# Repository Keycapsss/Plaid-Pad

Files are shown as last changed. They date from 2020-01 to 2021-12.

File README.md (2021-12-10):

# Plaid-Pad



A 4x4 numpad/macro pad with only through hole components. It supports up to 4 rotary encoder. The positions for the encoder are interchangeable with keyboard switches.  

---

- [**Build guide**](./buildguide_en.md)
- [QMK Firmware](#qmk-firmware)
- [Bootloader](#bootloader)
- [Changelog](#changelog)
- [3D printing parts](./3d-print) (simple case)
- [Laser cut drawings](./lasercut) (guard plate, dampening foam)

---

## Keymap



Below you can see the possible positions for the 4 rotary encoder (Rev1 only 2).  
*If you place a encoder in the top left corner (E1), you can't use another encoder in the lower right corner.*

```text
Rev2                      Rev1
,-----------------------,   ,-----------------------,
|  E1 |  E2 |  E3 |  E4 |   |  E1 |     |     |  E2 |
|-----+-----+-----+-----|   |-----+-----+-----+-----|
|     |     |     |  E3 |   |     |     |     |     |
|-----+-----+-----+-----|   |-----+-----+-----+-----|
|     |     |     |  E2 |   |     |     |     |     |
|-----+-----+-----+-----|   |-----+-----+-----+-----|
|     |     |     |  E1 |   |     |     |     |     |
`-----------------------'   `-----------------------'
```  

- Encoder E1 performs a tap on KC_F17 and KC_F18
- Encoder E2 performs a tap on KC_F19 and KC_F20
- Encoder E3 performs a tap on KC_F21 and KC_F22
- Encoder E4 performs a tap on KC_F23 and KC_F24

The F17-F24 keys are intended to be customized via [Karabiner-Elements](https://github.com/pqrs-org/Karabiner-Elements) (OSX), or [AutoHotkey](https://github.com/Lexikos/AutoHotkey_L) (WIN).

It's a great companion to the Plaid keyboard by [hsgw](https://github.com/hsgw/) and heavily inspired by it.

- Keyboard Maintainer: BenRoe [Github](https://github.com/BenRoe) / [Twitter](https://twitter.com/keycapsss)
- Hardware Supported: ATmega328P with VUSB ([see Bootloader section](#Bootloader))
- Hardware Availability: [Keycapsss.com](https://keycapsss.com)

## QMK Firmware

_Bootloader ([USBaspLoader](https://github.com/baerwolf/USBaspLoader)) and Firmware ([via keymap](https://github.com/qmk/qmk_firmware/tree/master/keyboards/keycapsss/plaid_pad)) are already on the ATmega328P chip._

### QMK with VIAL support (support for rotary encoder)

_Plaid-Pad Kit's Rev3 shipped with preflashed VIAL firmware._
_If you have a Rev2 Plaid-Pad, or want to re-flash the VIAL firmware again, you can find a compiled firmware file here ([Rev2]([keycapsss_plaid_pad_rev2_vial.hex](https://minhaskamal.github.io/DownGit/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)), [Rev3]([keycapsss_plaid_pad_rev3_vial.hex](https://minhaskamal.github.io/DownGit/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)))

1. Flash pre-compiled firmware on the Plaid-Pad with [QMK Toolbox](https://github.com/qmk/qmk_toolbox/releases) ([How to enter Bootloader Mode](#enter-bootloader-mode-to-flash-a-new-firmware)).
2. Download the VIAL software from [here](https://get.vial.today)
3. Connect the Plaid-Pad to the computer with a USB cable (Reconnect after flashing the firmware)
4. Open VIAL and change the keymap to your needs (automatic save)

### QMK with VIA support (no rotary encoder support)

_Plaid-Pad Kit's shipped before 11.09.2020 are flashed with the QMK Default Keymap._
_To use VIA, compile the VIA Keymap with the following command and flash it with [QMK Toolbox](https://github.com/qmk/qmk_toolbox/releases) on the Plaid-Pad ([enter Bootloader Mode](#enter-bootloader-mode-to-flash-a-new-firmware))._

```bash
qmk compile -kb keycapsss/plaid_pad -km via
```

1. Download the VIA software from [here](https://github.com/the-via/releases/releases/latest)
2. Connect the Plaid-Pad to the computer with a USB cable
3. Open VIA, switch to the `CONFIGURE` tab and change the keymap to your needs (automatic save)

_The current VIA version can't change the rotary encoder function._

### QMK Default Keymap

Make example for this keyboard (after [setting up your build environment](https://docs.qmk.fm/#/getting_started_build_tools)):

```bash
make keycapsss/plaid_pad:default
```

or

```bash
qmk compile -kb keycapsss/plaid_pad -km default
```

Flashing example for this keyboard:

```bash
make keycapsss/plaid_pad:default:flash
```

or

```bash
qmk flash -kb keycapsss/plaid_pad -km default
```

See the [build environment setup](https://docs.qmk.fm/#/getting_started_build_tools) and the [make instructions](https://docs.qmk.fm/#/getting_started_make_guide) for more information. Brand new to QMK? Start with the [Complete Newbees Guide](https://docs.qmk.fm/#/syllabus).

You can find the rotary encoder code [here](https://github.com/qmk/qmk_firmware/blob/95bbd799a4f86dac37fdf2354e008d2fed7f6660/keyboards/keycapsss/plaid_pad/keymaps/via/keymap.c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).

## Bootloader

- same `usbasploader` as used for Plaid ([Instructions](https://github.com/hsgw/plaid/blob/master/doc/en/bootloader.md), [Repository](https://github.com/hsgw/USBaspLoader/tree/plaid))

### Enter Bootloader Mode (to flash a new firmware)

- Plug in the USB cable
- Push and hold RESET switch
- Push and hold BOOT switch
- Release RESET switch
- Release BOOT switch

alternative method:

- Unplug the USB cable
- Hold down the BOOT switch
- Plug in the USB cable
- Release the BOOT switch

alternative method ([Bootmagic Lite](https://docs.qmk.fm/#/feature_bootmagic?id=bootmagic-lite)):

- Unplug the USB cable
- Hold down the most top left key
- Plug in the USB cable
- Release the most top left key

If you succeed to enter bootloader mode, you can see usbasp in device manager, or `*** USBAsp device connected` in [QMK Toolbox](https://github.com/qmk/qmk_toolbox).

## CHANGELOG

### Rev1

- Initial pcb design
- Optional up to 2 Rotary Encoder

### Rev2 (Rev1.1)

- Pcb's with the label Rev1.1 are Rev2 (fixed with the second ordered batch)
- Optional: up to 4 Rotary Encoder
- Support for 3pin switches with the new top plate
- Add a small PLAID-PAD text beneath the USB-C connector

### Rev2.1

- Bigger solder pads for the USB-C connector
- Support for Choc V2 switches _(issue that the keycap touch the mounting screw, if bottoming out)_
- Changed case mounting style _(spacer go through the pcb and screwed on the top and bottom plate)_

### Rev3

- Support for a SSD1306 oled display (I2C Pins C4/C5)
- Removed the 2 indicator LEDs (Pin C4/C5)
- Added a power indicator LED
- Changed case mounting style back to the previous style (spacer mounted between mid PCB and bottom plate) - fix ChocV2 issue from REV2.1

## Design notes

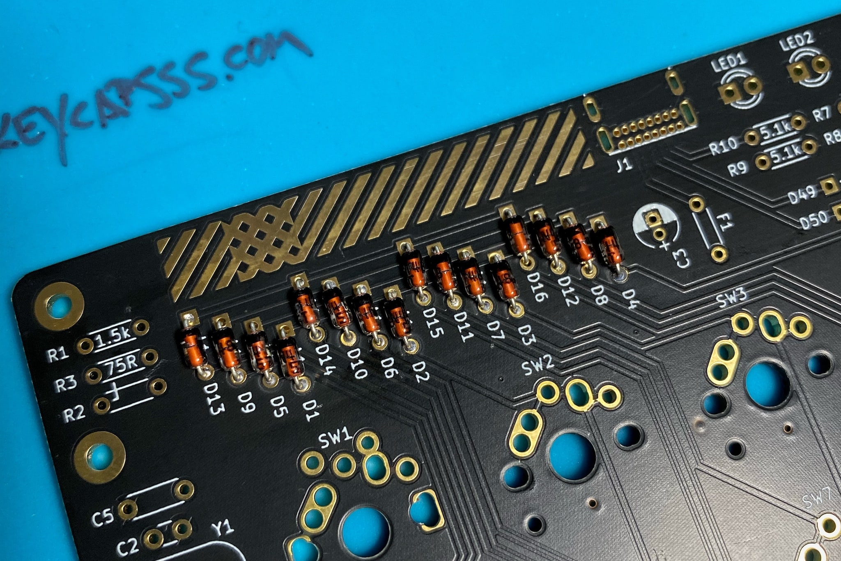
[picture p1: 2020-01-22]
img/plaid-pad-1N4148-diodes-2.jpg

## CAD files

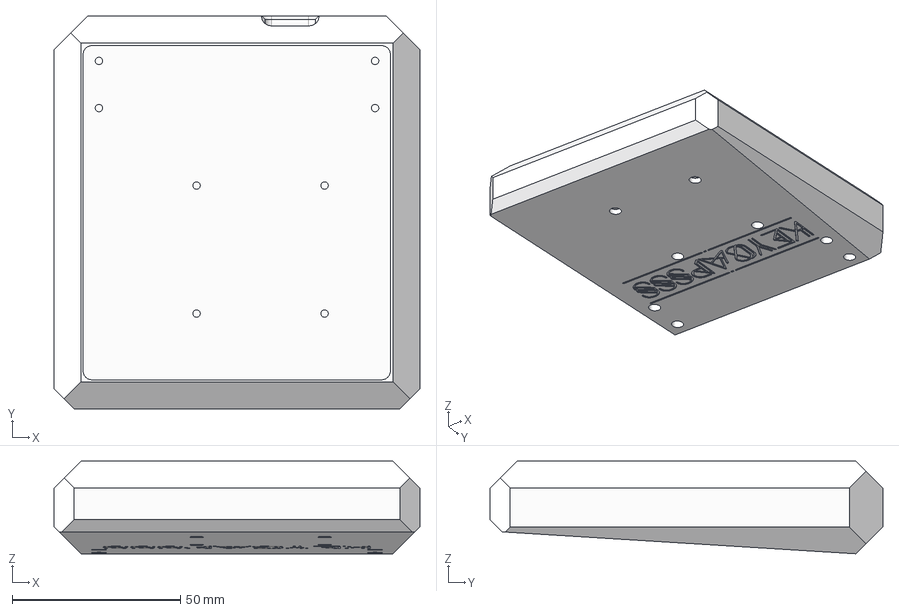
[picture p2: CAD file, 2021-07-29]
3d-print/angled-hexa-case/plaid-pad-case-hexa.step
108.7 x 116.7 x 27.5 mm

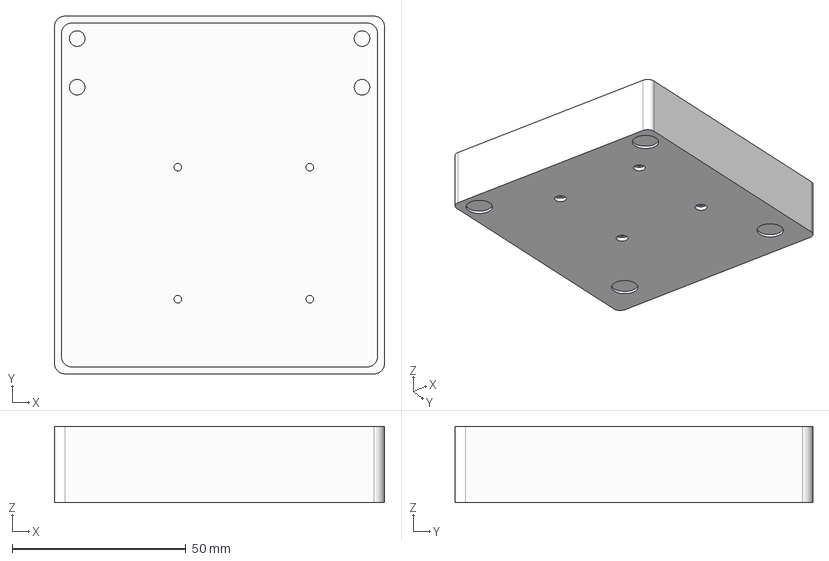
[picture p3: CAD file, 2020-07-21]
3d-print/IvoGoman/Plaid-Pad Case MX Hi-Pro Simple.step
95.0 x 103.0 x 22.0 mm

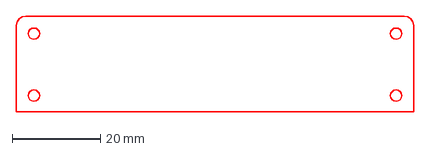
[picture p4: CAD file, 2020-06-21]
lasercut/plaid-pad-guard-cover.dxf
89.8 x 21.6 mm

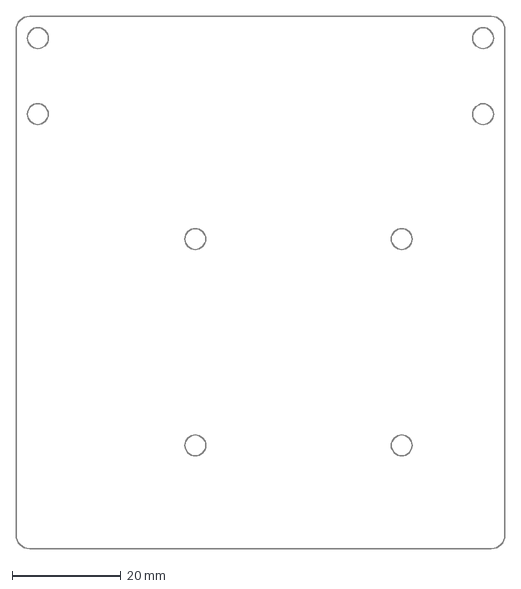
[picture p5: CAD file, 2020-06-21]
lasercut/plaid-pad-foam.dxf
90.0 x 98.0 mm

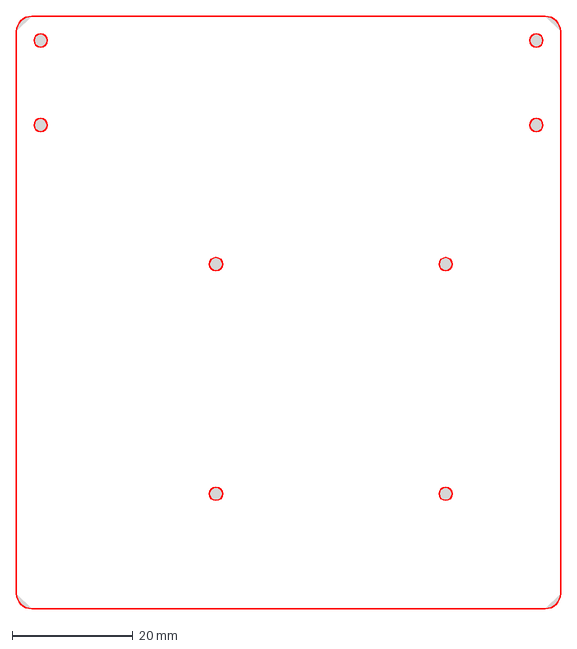
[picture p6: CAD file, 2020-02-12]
lasercut/plaid-pad-bottom-plate.dxf
90.0 x 98.0 mm

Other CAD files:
3d-print/Plaid-Pad Case MX Hi-Pro Simple.step
3d-print/IvoGoman/Plaid-Pad Case MX Hi-Pro Simple.f3d
3d-print/IvoGoman/Plaid-Pad Case MX Hi-Pro Simple.stl
3d-print/Plaid-Pad Case MX Hi-Pro Simple.f3d
3d-print/Plaid-Pad Case MX Hi-Pro Simple.stl
3d-print/angled-hexa-case/plaid-pad-case-hexa.3mf
3d-print/angled-hexa-case/plaid-pad-case-hexa.f3d
3d-print/angled-hexa-case/plaid-pad-case-hexa.stl

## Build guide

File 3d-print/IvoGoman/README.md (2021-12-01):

# Simple Case

Based on the original Simple Case design.

## Changes

1. Added notches for up to 1cm diameter bumpons on the bottom of the case
2. Added notches to the inside of the case. Not strictly necessary but makes the case compatible with the screws and stand-offs included in the kit. Otherwise you can simple use 4 additional 4mm M2 screws.

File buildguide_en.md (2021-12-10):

# Build guide for the Plaid-Pad

## Solder the through hole parts

### Diodes 1N4148 (D1-D16)

Diodes are __polarized__. The black line on the diode (cathode) must face the squared solder pad.
The 1N4148 diodes look similar as Zener diodes - so make sure that you don't confuse both diodes.

You can use some tape, as show in the image, to hold the diodes in place and solder all in one pass.

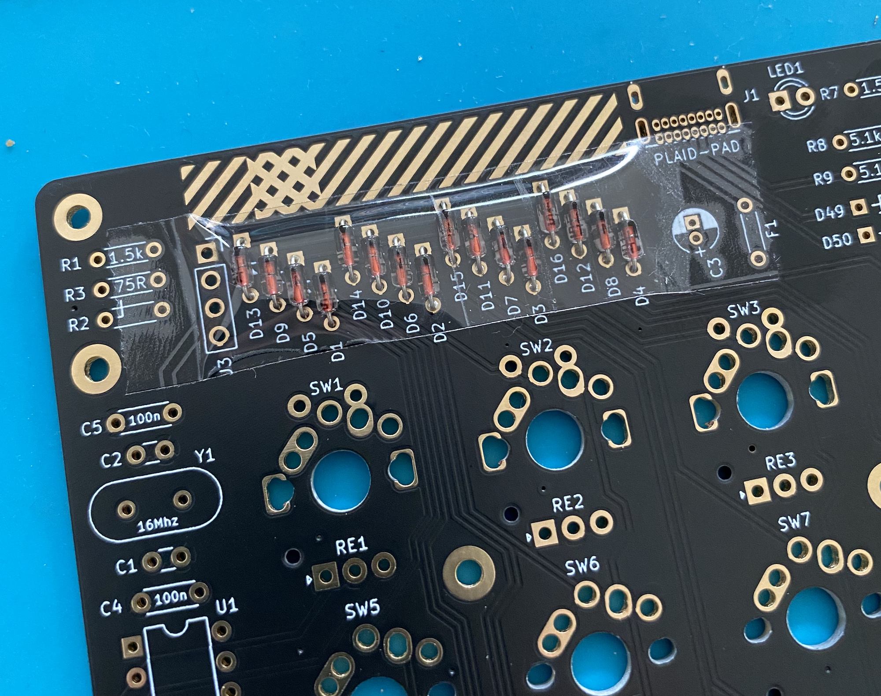
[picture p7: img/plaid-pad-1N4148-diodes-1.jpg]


### Zener diodes (D49, D50)

The diodes are __polarized__ where the black line on the diode (cathode) must face the squared solder pad.
The 1N4148 diodes look similar as Zener diodes - so make sure that you don't confuse both diodes.

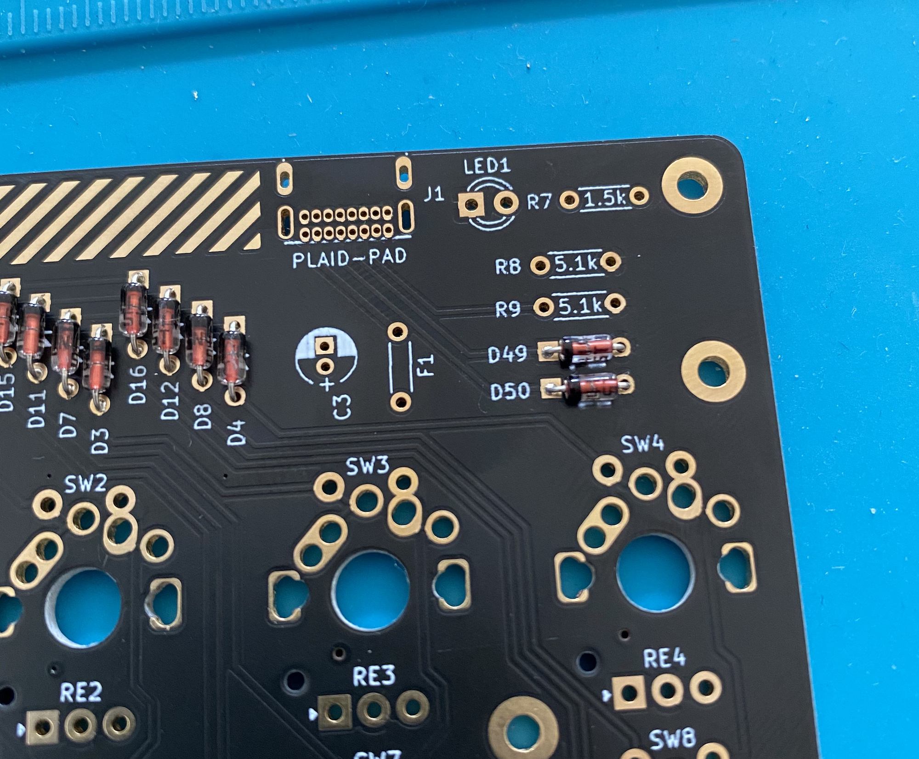
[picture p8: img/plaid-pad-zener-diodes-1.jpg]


### Resettable fuse (F1)

Attach and solder the fuse to `F1`. After soldering, bend the fuse like in the image.

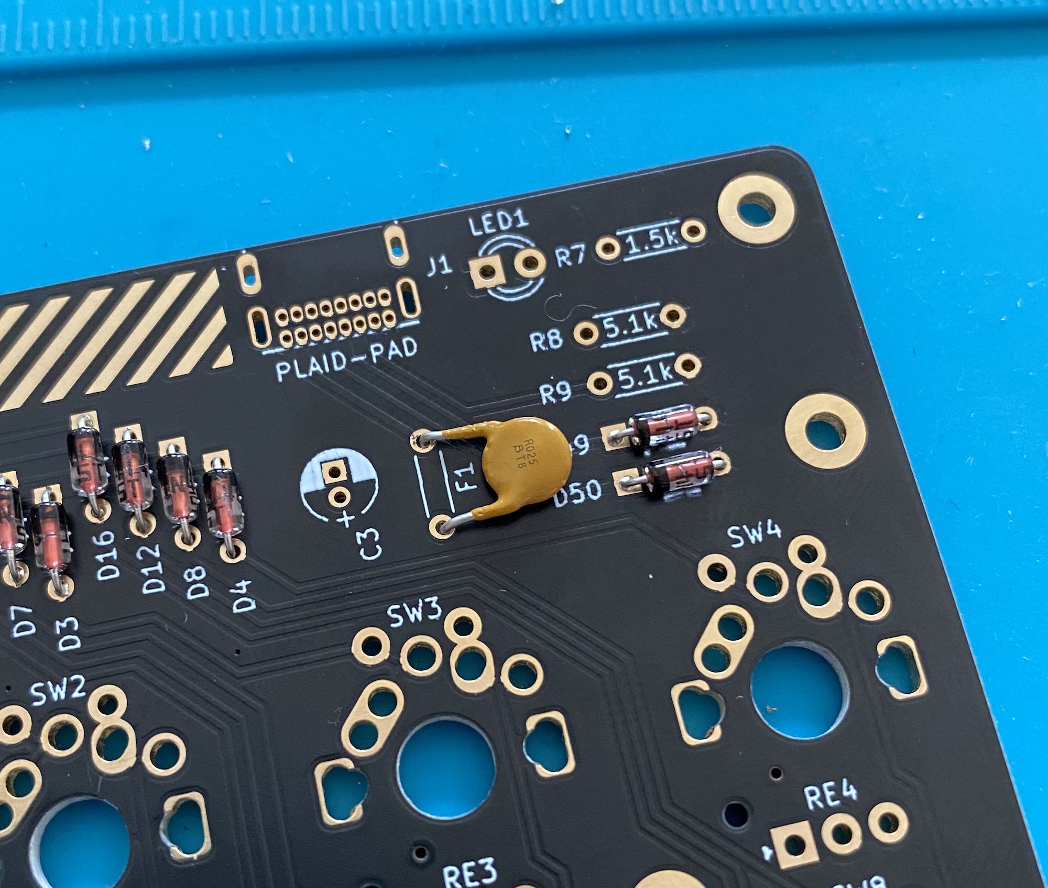
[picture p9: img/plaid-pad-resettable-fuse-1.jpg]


### Electrolytic capacitor (C3)

The Electrolytic capacitor is __polarized__. The short leg is cathode which needs to be attached to the square pad on the PCB.

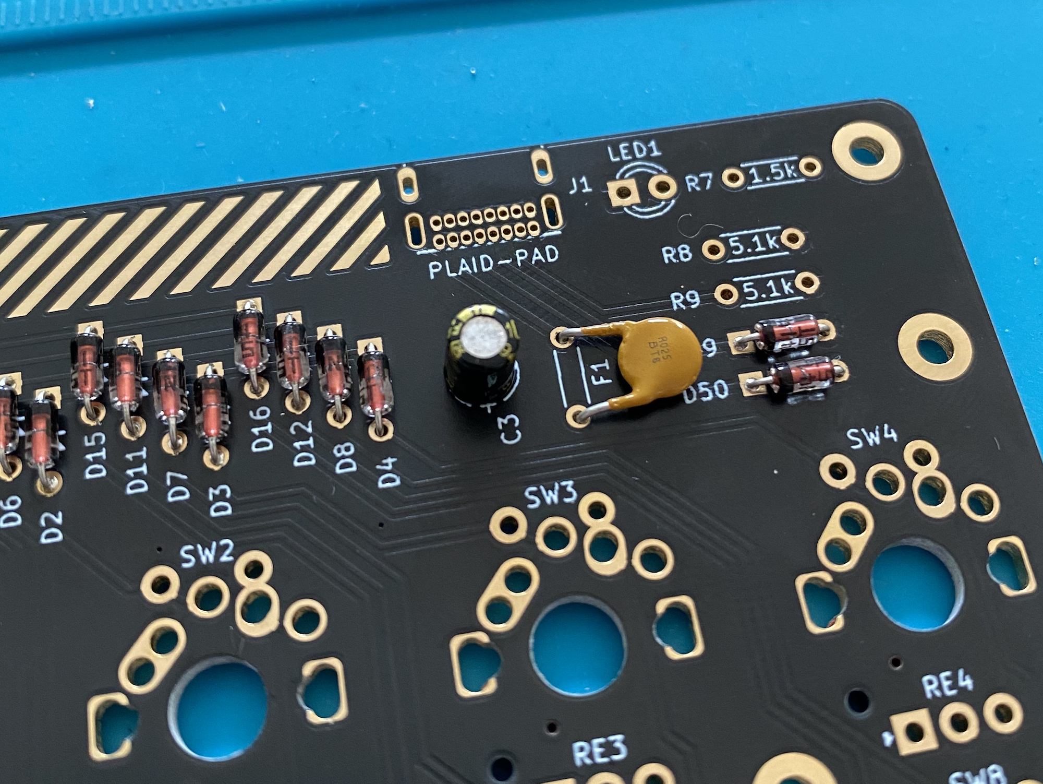
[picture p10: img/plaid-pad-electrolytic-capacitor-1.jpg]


### Resistors 1.5k Ohm (R1, R7)

Attach the resistors with following colors from left to right:

- brown, green, black, brown, brown

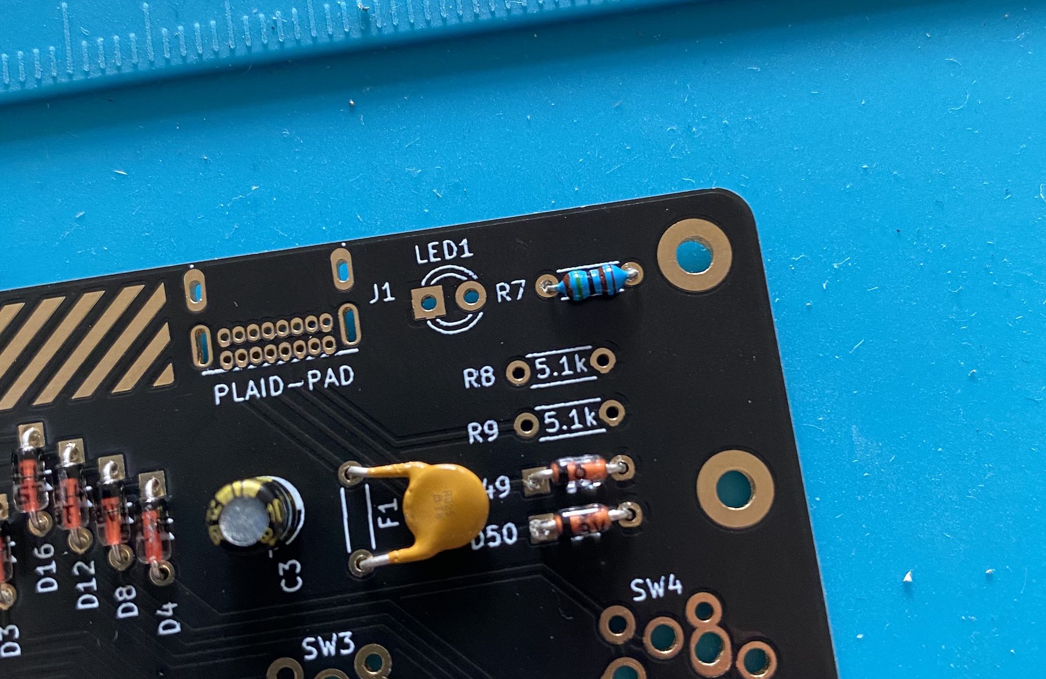
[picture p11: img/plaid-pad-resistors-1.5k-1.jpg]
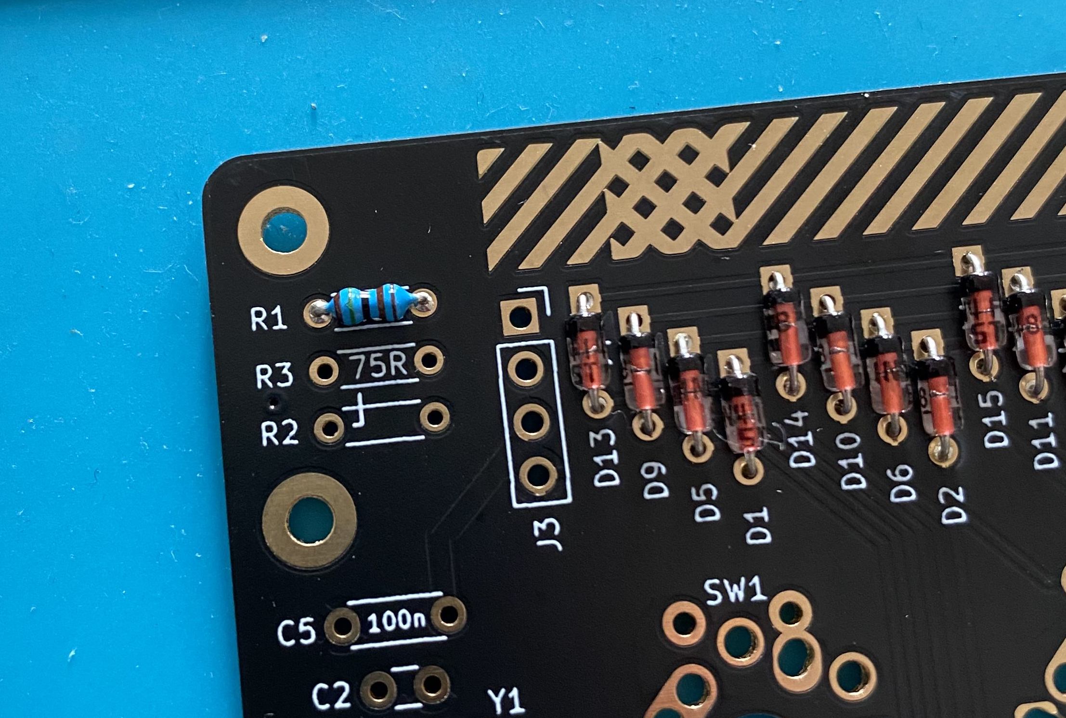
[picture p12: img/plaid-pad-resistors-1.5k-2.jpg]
 

### Resistors 75 Ohm (R2, R3)

Attach the resistors with following colors from left to right:

- brown, gold, black, green, purple

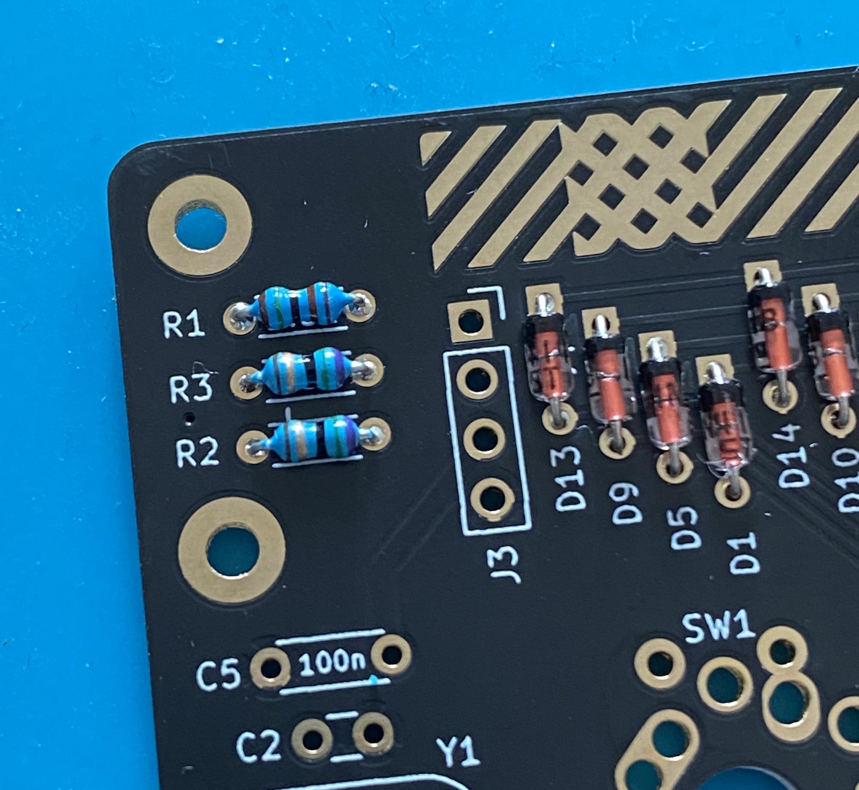
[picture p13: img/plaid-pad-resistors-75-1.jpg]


### Resistors 10k Ohm (R4)

Attach the resistors with following colors from left to right:

- brown, black, black, red, brown

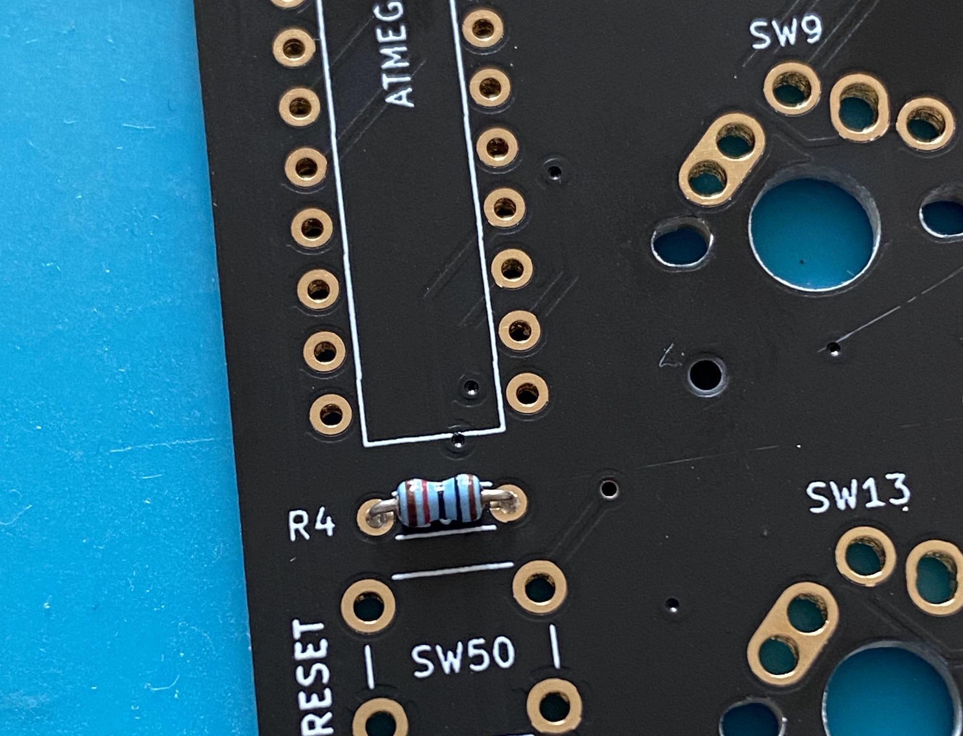
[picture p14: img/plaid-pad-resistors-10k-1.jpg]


### Resistors 5.1k Ohm (R8, R9)

Attach the resistors with following colors from left to right:

- green, brown, black, brown, brown

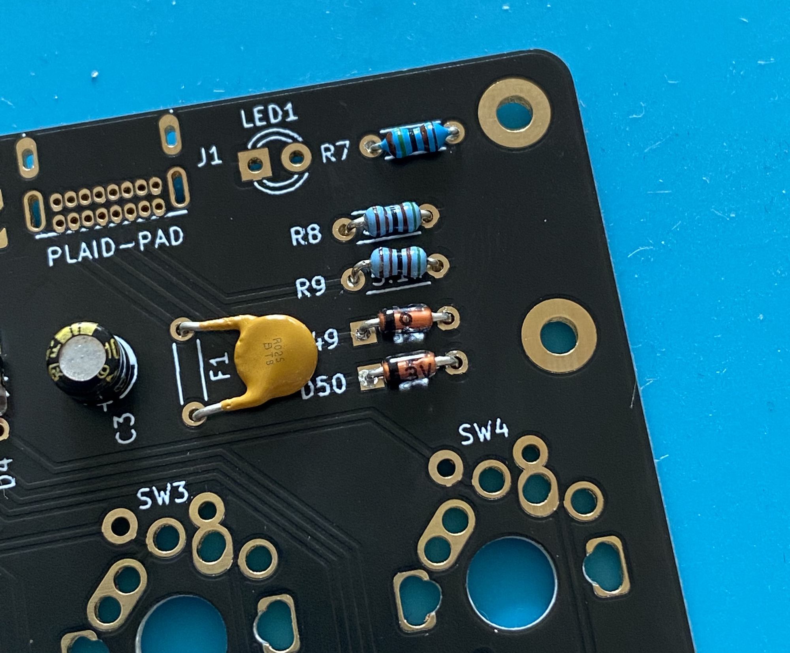
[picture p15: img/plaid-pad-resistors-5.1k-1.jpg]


### USB-C connector (J1)

Double check that there are no short cuts between the solder pads.
A magnifier is handy for this task.

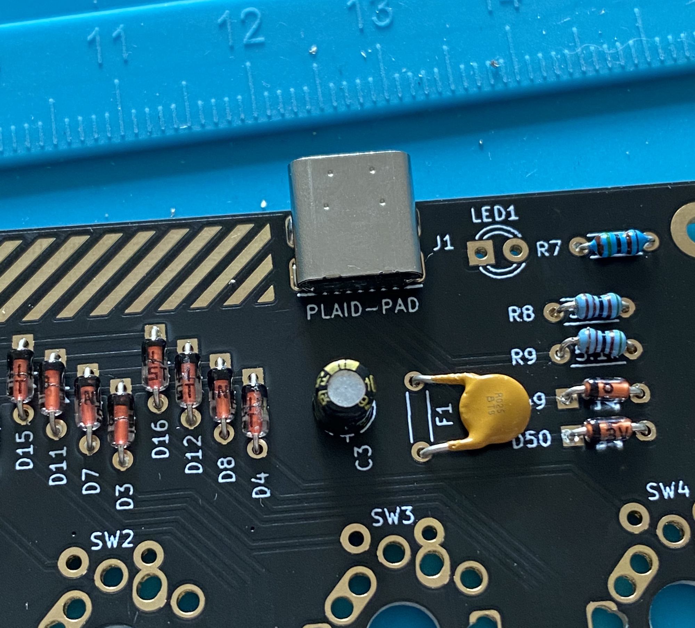
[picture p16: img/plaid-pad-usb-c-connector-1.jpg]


### Optional: LED (LED1)

The LEDs are __polarized__. The short leg is the cathode which needs to be attached to the square pad on the PCB

`LED1` indicates that the Plaid-Pad is powered and constantly on.

If you don't want a constant red light on your Plaid-Pad, don't solder this LED.

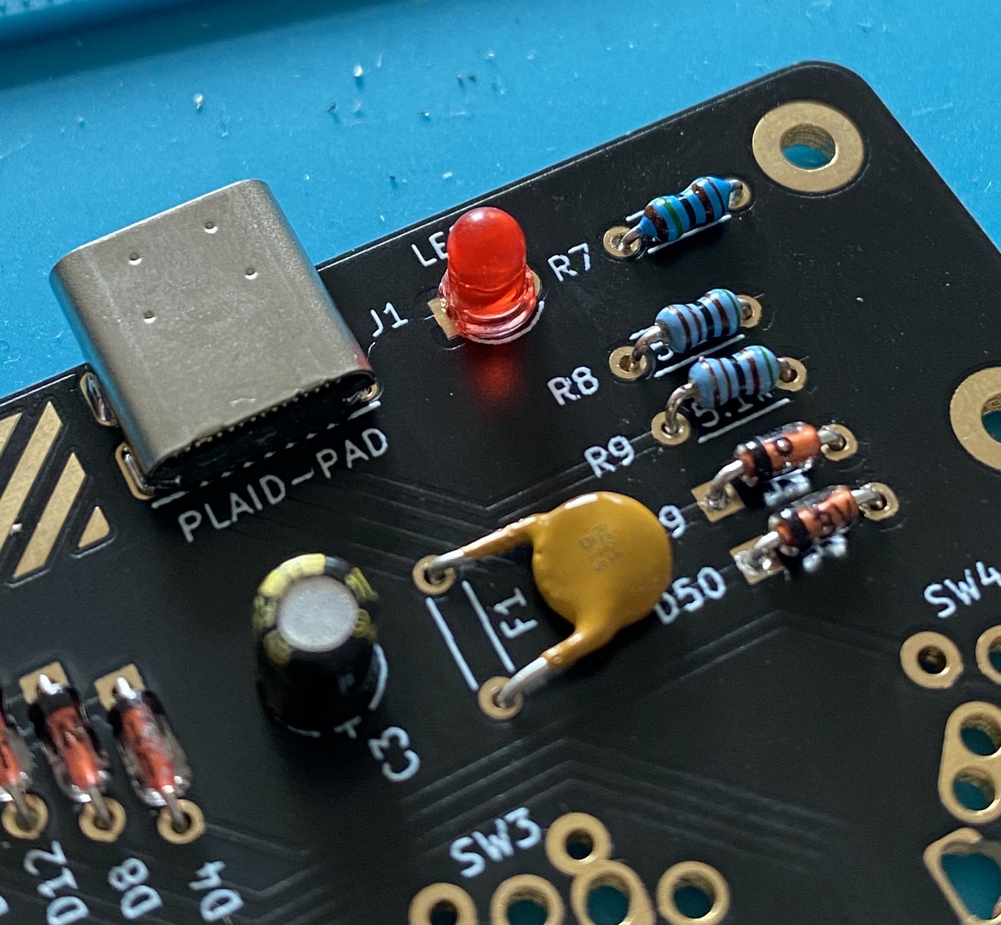
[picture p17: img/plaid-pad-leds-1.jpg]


### Crystal (Y1)

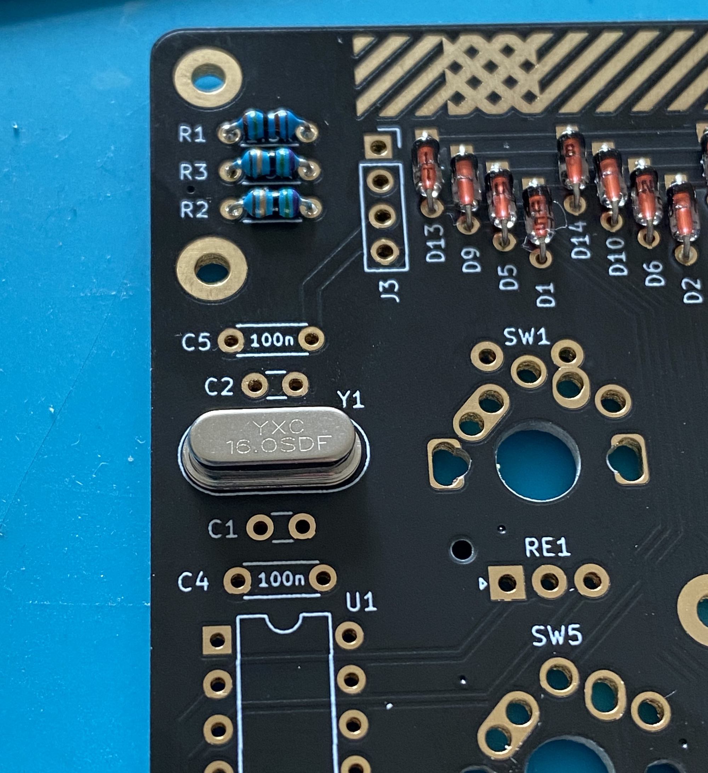
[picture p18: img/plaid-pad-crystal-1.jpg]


### Capacitors 22pF (C1, C2)

They have a small pitch (2.5mm).

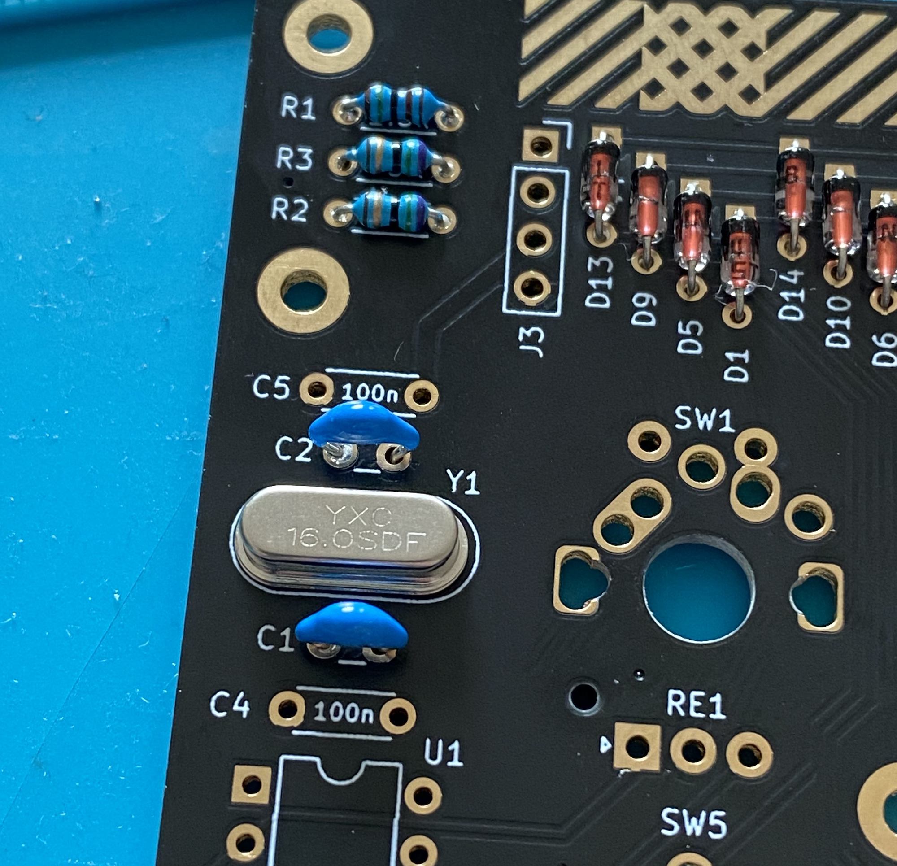
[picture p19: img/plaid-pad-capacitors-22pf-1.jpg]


### Capacitors 0.1uF (C4, C5)

These have a larger pitch of 5mm.

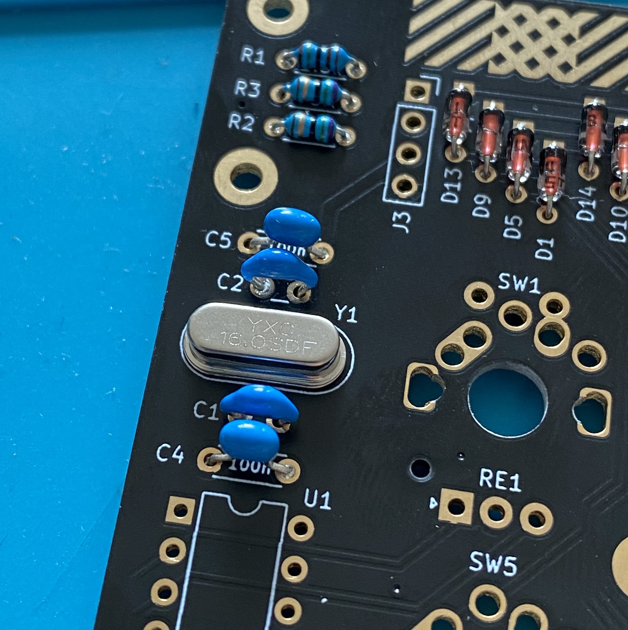
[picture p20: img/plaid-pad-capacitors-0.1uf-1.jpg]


### IC socket U1

The IC socket is __polarized__. Check the notch on the silk and the IC Socket.

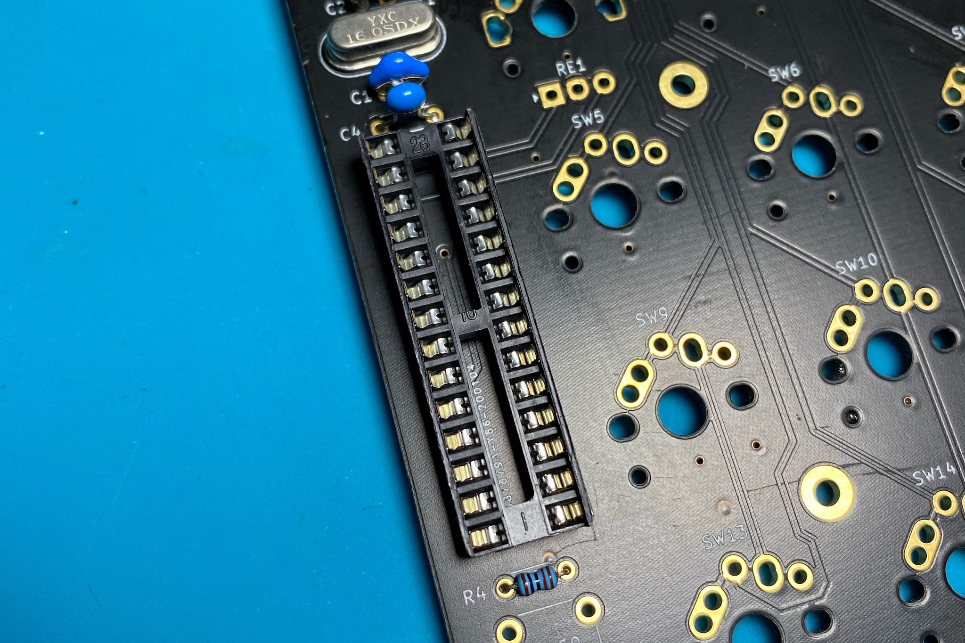
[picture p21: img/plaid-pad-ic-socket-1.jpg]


### Tactile switch (SW50/RESET, SW51/BOOT)

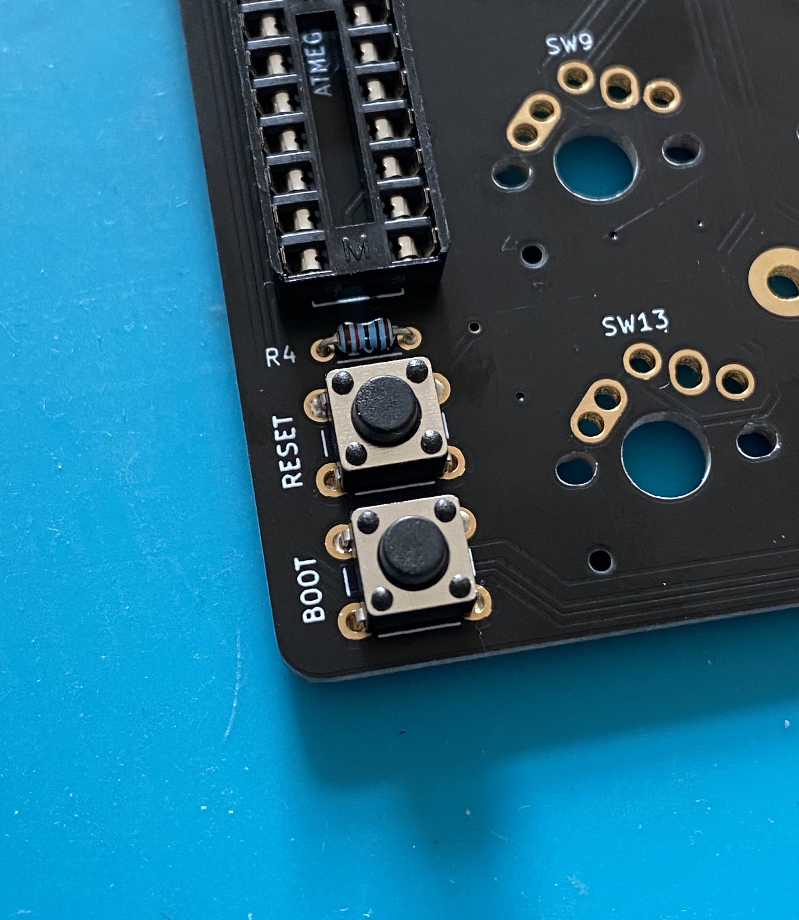
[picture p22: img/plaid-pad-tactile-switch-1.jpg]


### ATMEGA328p chip

The ATMEGA328 has to be attached in a __specific direction__. Check the notch on the chip and IC Socket - they need to match. Here, the notch faces the crystal at `Y1`.

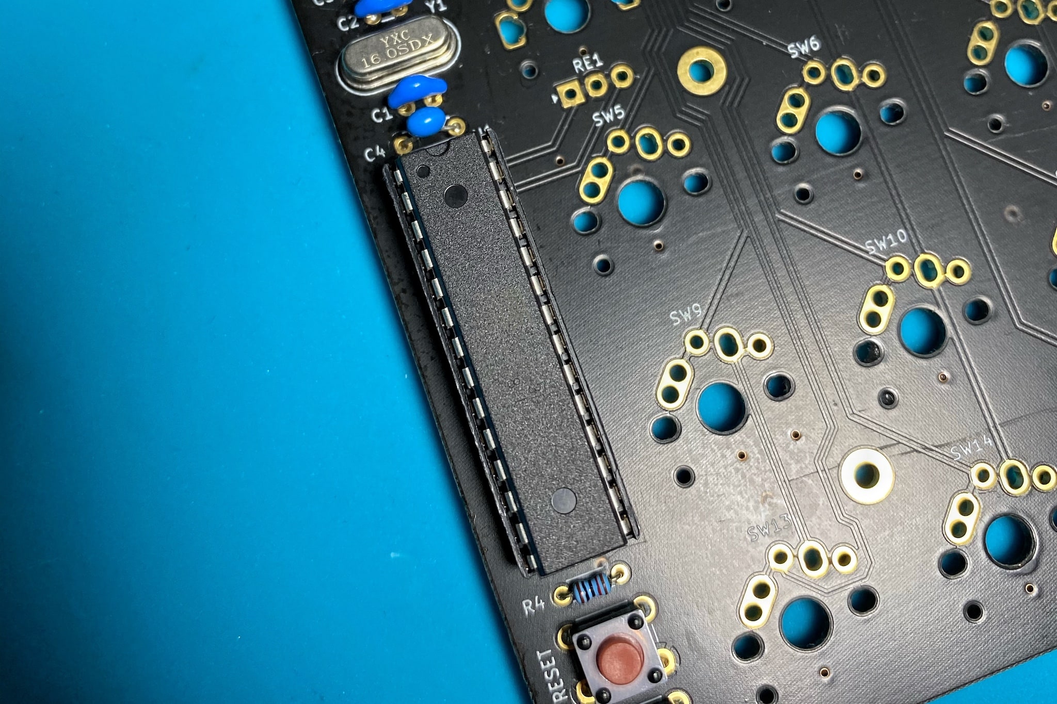
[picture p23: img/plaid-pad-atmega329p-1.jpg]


### OLED display (SSD1306)

Add isolation tape to the back of the OLED, to protect the components for shorts.

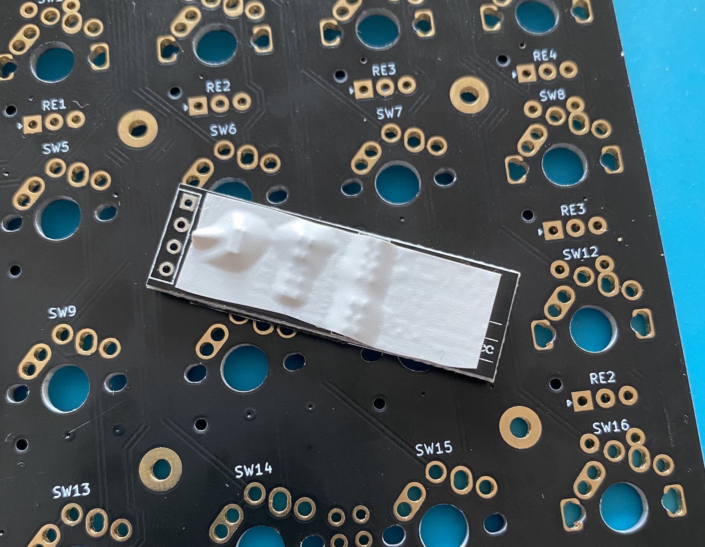
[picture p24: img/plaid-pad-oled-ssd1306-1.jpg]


Place the OLED like on the image and solder it from the bottom to the PCB.

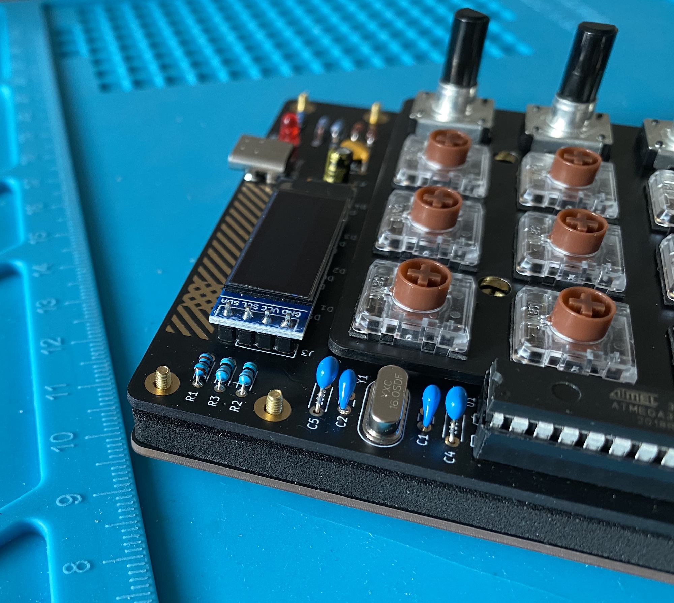
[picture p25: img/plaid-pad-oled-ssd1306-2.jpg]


## Check list before connecting USB

- No short cuts on the USB-C connector pads
- Direction of polarized and directional components is correct (ATMEGA328p, diode, resettable fuse, electrolytic capacitor, LEDs)
- Resistors with correct values are attached to the target locations

## Test

_Bootloader and Firmware (VIA keymap) are already on the ATmega328P chip.  
Everything should work after soldering._

Connect the Plaid-Pad to your computer and open the [QMK-Test-Site](https://config.qmk.fm/#/test).

Check whether all switches will work. To do so, short the solder pads with tweezers.

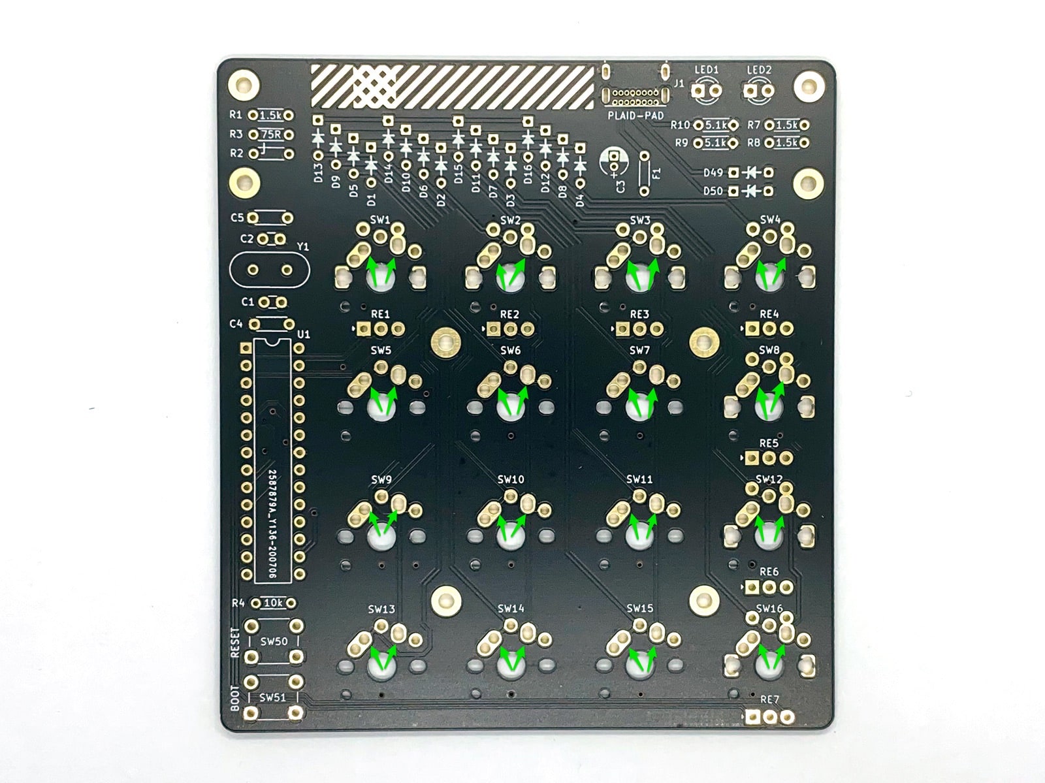
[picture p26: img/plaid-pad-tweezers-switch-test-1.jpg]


## Optional Mill-Max holtites

The Plaid-Pad supports [Mill-Max 0305 Holtites](https://keycapsss.com/keyboard-parts/parts/73/mill-max-0305-holtite-for-switches-hotswap-sockets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). If these are installed, you can Hotswap the switches (change without soldering).

Put the holtite in the related holes.

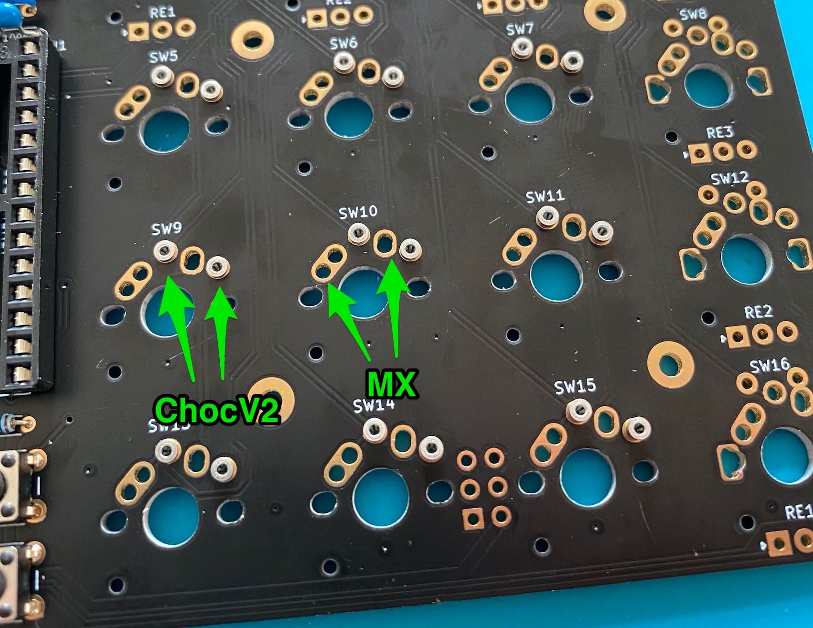
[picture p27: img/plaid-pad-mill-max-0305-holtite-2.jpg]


Install all switches to the top plate. Check that all switch pins are straight and press the top plate with switches on the PCB with the holtites.

Pay attention that no solder flows into the holtite.

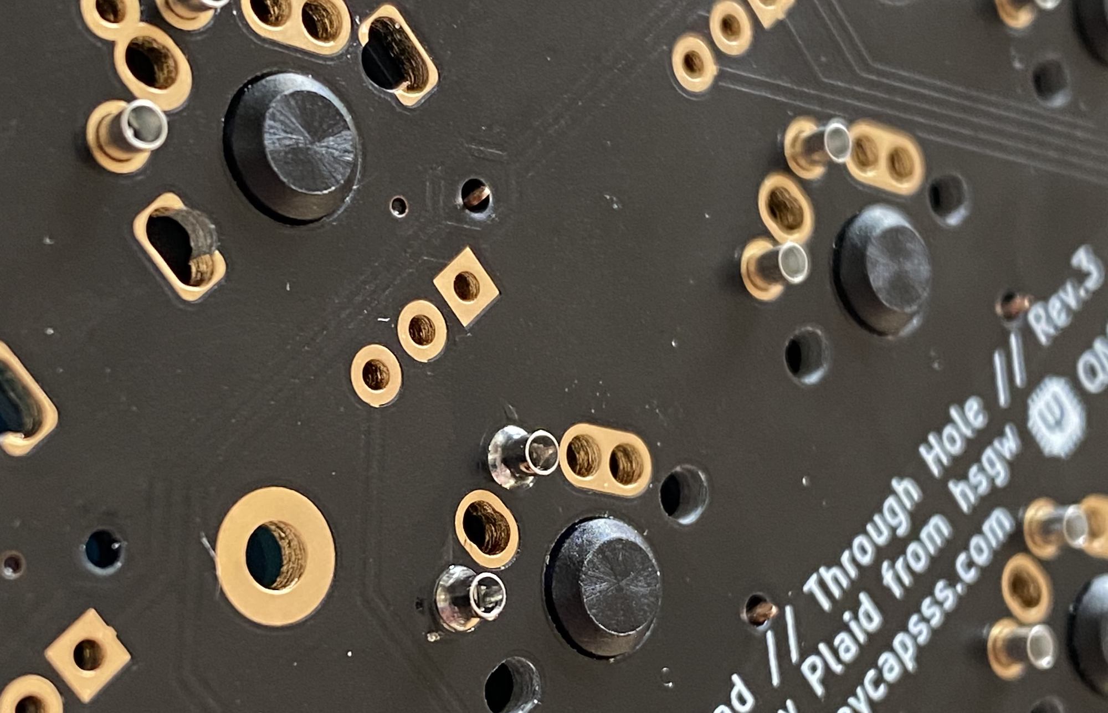
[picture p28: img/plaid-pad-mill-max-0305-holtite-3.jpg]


## Case assembly

__Before you solder the switches,__ attach the 4x 5mm spacer to the pcb with the M2x4mm screws.  
__Don't solder the rotary encoder yet.__

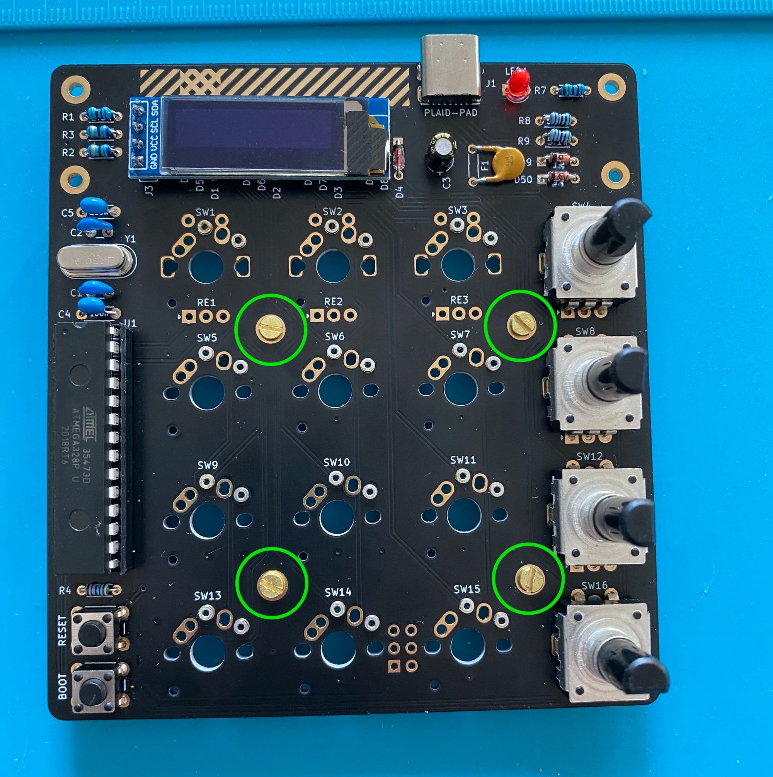
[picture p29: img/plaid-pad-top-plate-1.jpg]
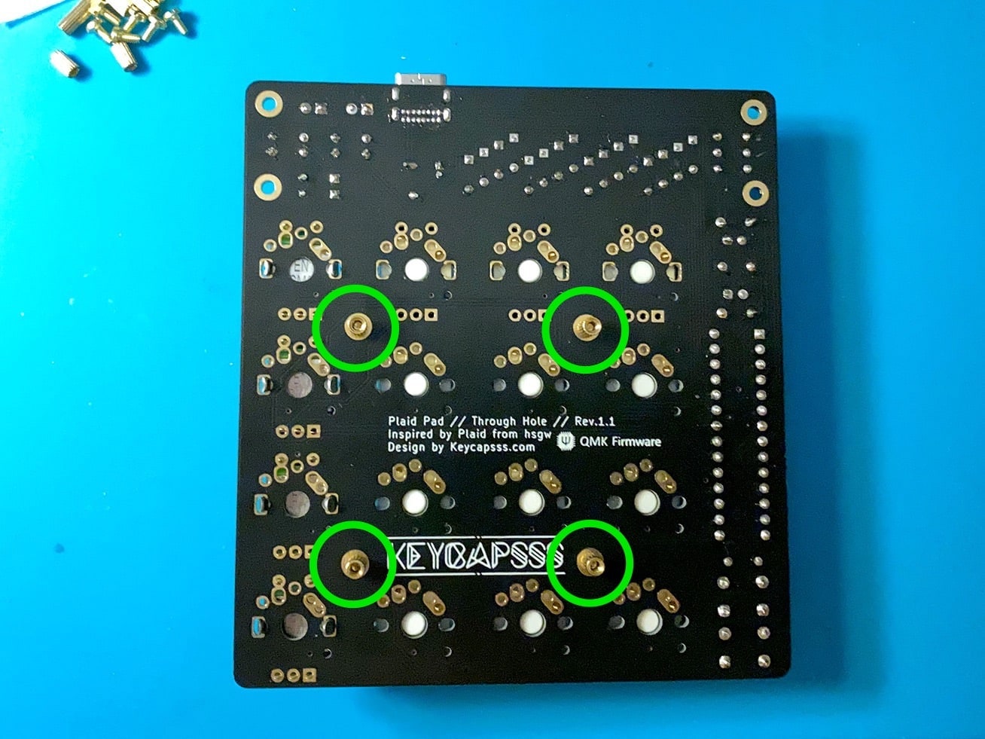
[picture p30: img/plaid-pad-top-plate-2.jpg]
 

Attach all switches to the top plate and place __(not solder)__ the desired amount of the rotary encoder on the pcb ([more information about rotary encoder placement](https://github.com/BenRoe/Plaid-Pad#keymap)).

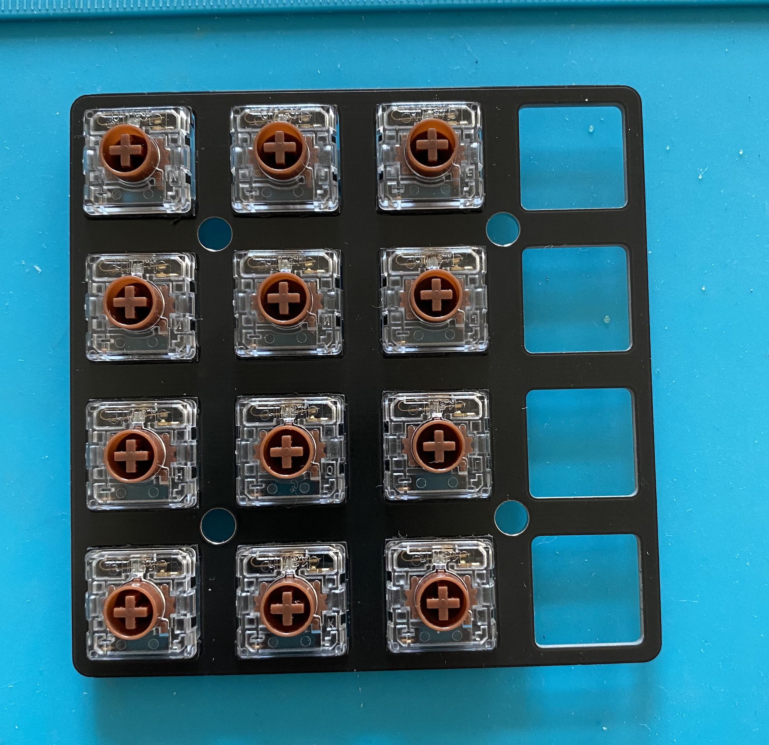
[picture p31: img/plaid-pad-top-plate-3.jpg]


This way the rotary encoder have room to move and fit perfect into the top plate cutout.

### Rotary encoder and Choc (low profile) switches (skip if you use MX switches)

If you use Choc (low profile) switches, you have to bend the 5 pins of the rotary encoder with a pliers, to fit into the top plate.

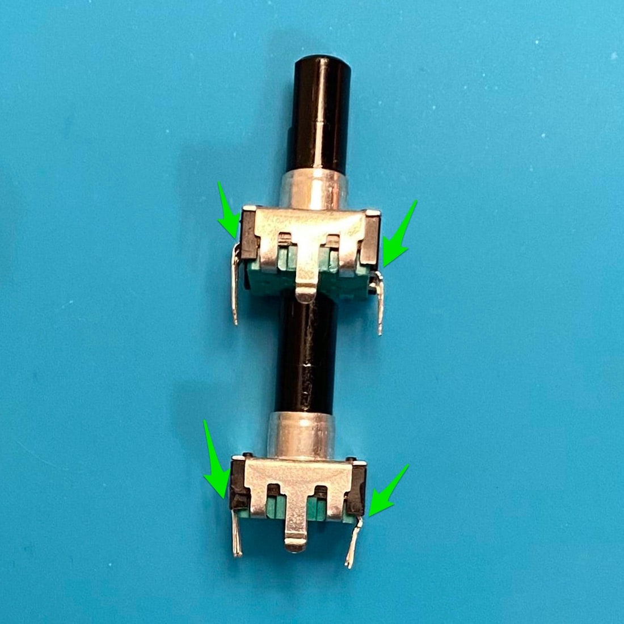
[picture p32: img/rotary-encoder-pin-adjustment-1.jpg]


---

Put the top plate with the switches on the front side of the pcb.  
Solder the switches and rotary encoder from the bottom side.  
__Ensure that there is no gap between the switch bottom and the pcb. Same for the encoder.__

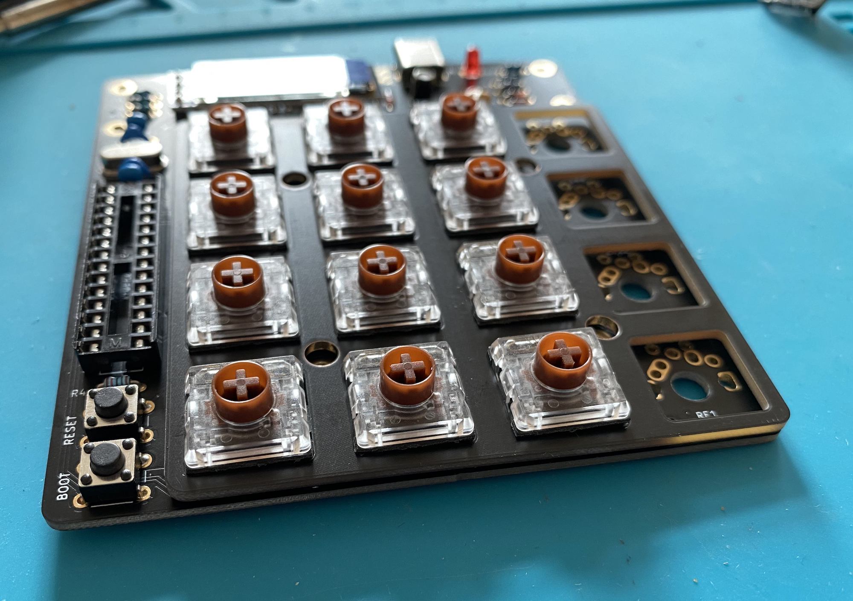
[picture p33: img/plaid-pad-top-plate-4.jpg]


Screw the 4x 5mm spacer at the upper part of the bottom plate. Use the 12mm (10mm) screws for it.

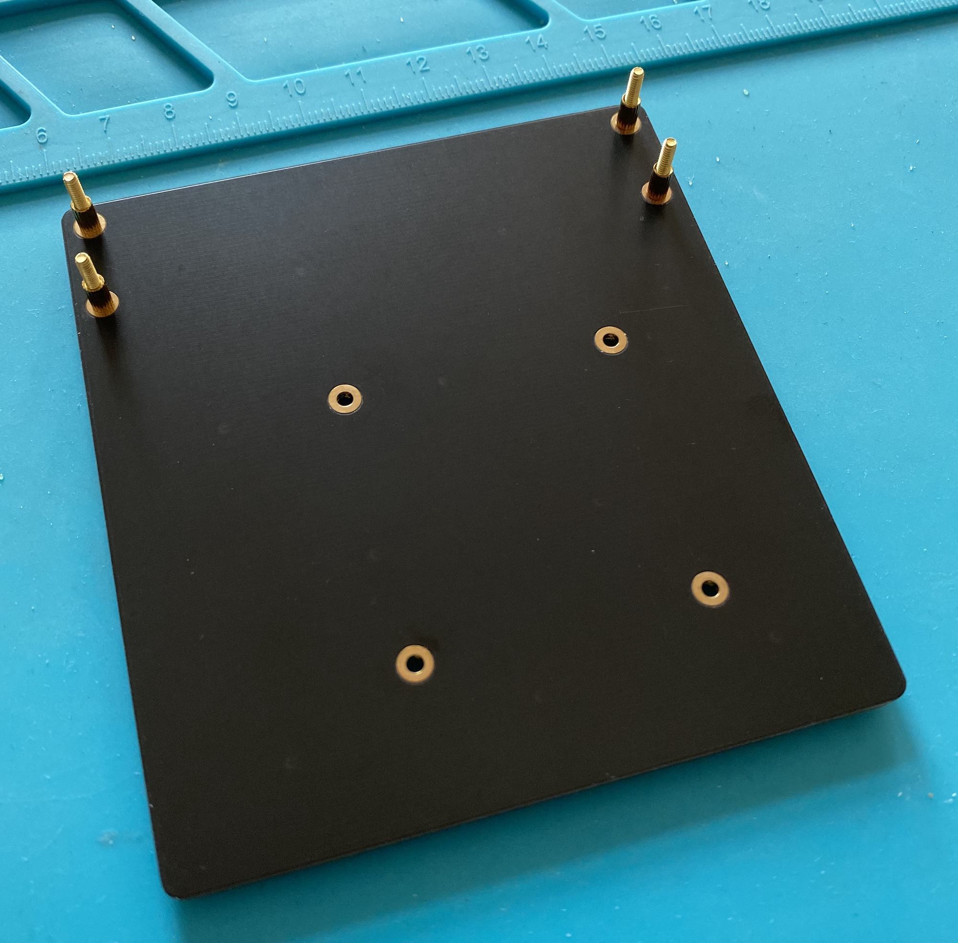
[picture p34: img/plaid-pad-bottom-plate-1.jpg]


Optional: Put the dampening foam on the bottom plate.

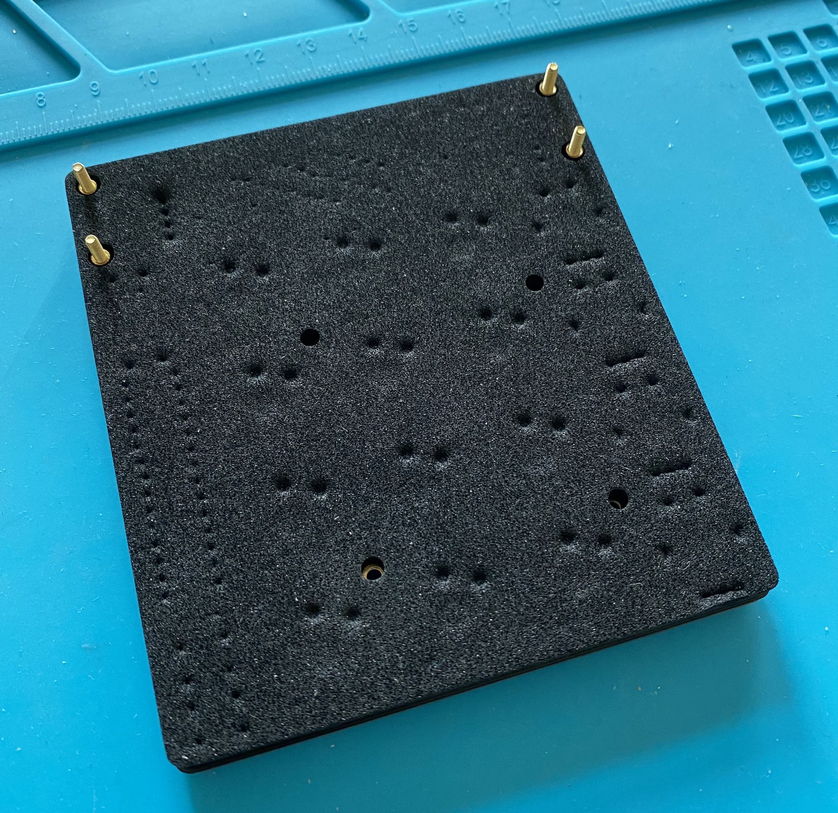
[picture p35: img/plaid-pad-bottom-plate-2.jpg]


Put the assembled top plate with the switches and pcb on the bottom plate.  

Screw the 4x 10mm spacer for the guard plate on 12mm (10mm) prominent screws from below.
Remove the protection film on both sides from the acrylic guard plate.
Fix the acrylic guard plate and the pcb with the 4mm screws.

__Don't overtighten the screws, the acrylic plate can break.__

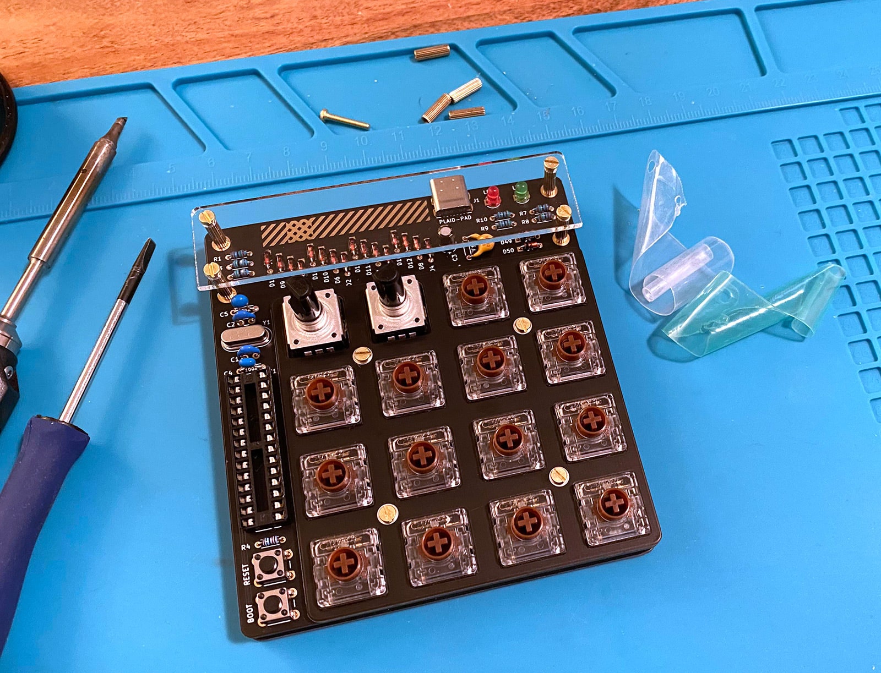
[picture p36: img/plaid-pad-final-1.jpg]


Put the rubber feeds on the back of the Plaid-Pad.

__The assembly is done.__ 🥳
  
You can change the keymap with [VIA](./README.md#qmk-with-via-support-no-rotary-encoder-support) (**no** rotary encoder support), [VIAL](https://get.vial.today) (with rotary encoder support),
or change the [QMK keymap](https://github.com/BenRoe/Plaid-Pad#qmk-default-keymap) file and reflash the firmware.

## How to flash the firmware

### QMK with VIAL support (support for rotary encoder)

_Plaid-Pad Kit's Rev3 shipped with preflashed VIAL firmware._

If you have a Rev2 Plaid-Pad, or want to re-flash the VIAL firmware again, you can find a compiled firmware file here ([Rev2]([keycapsss_plaid_pad_rev2_vial.hex](https://minhaskamal.github.io/DownGit/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)), [Rev3]([keycapsss_plaid_pad_rev3_vial.hex](https://minhaskamal.github.io/DownGit/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)))

1. Flash pre-compiled firmware on the Plaid-Pad with [QMK Toolbox](https://github.com/qmk/qmk_toolbox/releases) ([How to enter Bootloader Mode](#enter-bootloader-mode-to-flash-a-new-firmware)).
2. Download the VIAL software from [here](https://get.vial.today)
3. Connect the Plaid-Pad to the computer with a USB cable (Reconnect after flashing the firmware)
4. Open VIAL and change the keymap to your needs (automatic save)

### QMK with VIA support (no rotary encoder support)

To use VIA, compile the VIA Keymap with the following command and flash it with [QMK Toolbox](https://github.com/qmk/qmk_toolbox/releases) on the Plaid-Pad ([enter Bootloader Mode](#enter-bootloader-mode-to-flash-a-new-firmware)).

```bash
qmk compile -kb keycapsss/plaid_pad -km via
```

1. Download the VIA software from [here](https://github.com/the-via/releases/releases/latest)
2. Connect the Plaid-Pad to the computer with a USB cable
3. Open VIA, switch to the `CONFIGURE` tab and change the keymap to your needs (automatic save)

_The current VIA version can't change the rotary encoder function._

### QMK Default Keymap

Make example for this keyboard (after [setting up your build environment](https://docs.qmk.fm/#/getting_started_build_tools)):

```bash
make keycapsss/plaid_pad:default
```

or

```bash
qmk compile -kb keycapsss/plaid_pad -km default
```

Flashing example for this keyboard:

```bash
make keycapsss/plaid_pad:default:flash
```

or

```bash
qmk flash -kb keycapsss/plaid_pad -km default
```

See the [build environment setup](https://docs.qmk.fm/#/getting_started_build_tools) and the [make instructions](https://docs.qmk.fm/#/getting_started_make_guide) for more information. Brand new to QMK? Start with the [Complete Newbees Guide](https://docs.qmk.fm/#/syllabus).

You can find the rotary encoder code [here](https://github.com/qmk/qmk_firmware/blob/95bbd799a4f86dac37fdf2354e008d2fed7f6660/keyboards/keycapsss/plaid_pad/keymaps/via/keymap.c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).

## Bootloader

- same `usbasploader` as used for Plaid ([Instructions](https://github.com/hsgw/plaid/blob/master/doc/en/bootloader.md), [Repository](https://github.com/hsgw/USBaspLoader/tree/plaid))

### Enter Bootloader Mode (to flash a new firmware)

- Plug in the USB cable
- Push and hold RESET switch
- Push and hold BOOT switch
- Release RESET switch
- Release BOOT switch

alternative method:

- Unplug the USB cable
- Hold down the BOOT switch
- Plug in the USB cable
- Release the BOOT switch

alternative method ([Bootmagic Lite](https://docs.qmk.fm/#/feature_bootmagic?id=bootmagic-lite)):

- Unplug the USB cable
- Hold down the most top left key
- Plug in the USB cable
- Release the most top left key

If you succeed to enter bootloader mode, you can see usbasp in device manager, or `*** USBAsp device connected` in [QMK Toolbox](https://github.com/qmk/qmk_toolbox).

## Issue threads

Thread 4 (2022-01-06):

Add documentation for components that are not included in the kit

TeaganBrend, 2022-01-06:
Plaid-Pad is a DIY kit but a BOM is not readily available.

Complete info available is:
- Optional: rotary encoder (0-4x)
- Optional: Oled display (SSD1306 - 0.91 Inch 128x32 I2C)

SSD1306 describes an OLED display, but the board requires a module on a board with a 0.1" header. The module is available from Keycapsss but not most other vendors. If possible, more vendors should be linked in the build guide, as shipping from the EU for a small item that was missed in the order is expensive.

Same goes for encoder. The with detent part number offered by keycapsss is the en11-hsb1af20, no part number is provided for the no detent version. ALPSALPINE is given as the manufacturer, but their EC11 line (most close match) doesn't have a flat shaft without detents except in the EC111 family which would not be 18ppr. The Footprint given is an EC11E, closest match is as described on site but with detents, which would make the fully qualified part number EC11E18244A5 (flat shaft, 20mm shaft, 10+/-7mNm torque, 36 detents, 18 ppr, with push-on switch, 1.5mm travel). This part is readily available in distribution, some vendors could be linked (eg Newark, Avnet, Mouser)

Lastly, the recommended part number for the hotswap sockets should be listed (Mill-Max ‎0305-2-15-15-47-27-10-0‎)

Closed 2022-02-20.

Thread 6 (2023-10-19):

Schematics missing.

dreirund, 2023-10-19:
Ahoj,

I miss the schematics of the device.

Where are they available? Can they be added to this repository (als SVG/PDF and maybe also some schematics editor file like KiCad)?

Regards!

BenRoe, 2023-10-20:
Hi,
the Plaid-Pad is heavily based on the Plaid by hsgw.
You can find the Plaid Schematic here.
https://github.com/hsgw/plaid/tree/master/pcb

dreirund, 2023-10-20:
> *Hi, the Plaid-Pad is heavily based on the Plaid by hsgw. You can find the Plaid Schematic here. https://github.com/hsgw/plaid/tree/master/pcb*

"*heavily based on*" makes it even more difficult to exactly spot the differences.
This makes the need for a schematic that actually covers the real state even bigger in my opinion.

Regards and thanks for the reference!

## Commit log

2020-01-21 Add drawing for the acrylic guard plate
2020-01-21 Add resistor color code to build guide
2020-01-22 Add polarized hint ot led section.
2020-02-12 Add drawing for the bottom plate
    [plaid-pad-bottom-plate.dxf]
2020-06-21 update the simple 3d print case
    - the top of the case should align with the top of the guad plate now
    [Plaid-Pad Case MX Hi-Pro Simple.f3d, Plaid-Pad Case MX Hi-Pro Simple.step, Plaid-Pad Case MX Hi-Pro Simple.stl]
2020-06-21 add drawing for the dampening foam
    [plaid-pad-foam.dxf]
2020-06-21 add drawing for the guard plate
    [plaid-pad-guard-cover.dxf]
2020-07-11 Added notches on case inside for screws and under the case for up to 1cm diameter bumpons
    [Plaid-Pad Case MX Hi-Pro Simple.f3d, Plaid-Pad Case MX Hi-Pro Simple.step, Plaid-Pad Case MX Hi-Pro Simple.stl]
2020-07-18 Move files to new subfolder and add readme
    [Plaid-Pad Case MX Hi-Pro Simple.f3d, Plaid-Pad Case MX Hi-Pro Simple.step, Plaid-Pad Case MX Hi-Pro Simple.stl]
2020-09-01 add encoder positions
2020-09-01 update encoder overview for rev1
2020-09-16 Add encoder informations
2020-09-23 add info how to use top plate
2020-11-09 move laser cut drawings to the designated folder
    [plaid-pad-bottom-plate.dxf]
2020-11-09 add notes for encoder code location
2021-04-06 Add hint for guard plate screws
2021-07-29 add the 3d printable angled hexa case
    [plaid-pad-case-hexa.3mf, plaid-pad-case-hexa.f3d, plaid-pad-case-hexa.step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]
2021-09-29 update vial firmware for rev3
    - better encoder position in vial gui
    - fixed layout in gui
2022-06-29 feature: add svg for the top plate
